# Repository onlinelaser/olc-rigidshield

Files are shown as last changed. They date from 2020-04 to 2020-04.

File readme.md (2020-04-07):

## RIGIDSHIELD v1

This is a disposable and/or reusable face shield design, that is 95% laser cut.

It's based strongly on a design from a US university that I can no longer find. If it's yours please raise a pull request so I can attribute it properly!

Our modifications based on hospital feedback have included:

1) Increasing the wrap of the shield

2) Adding a top cover to help reduce liquid penetration to the face

3) Changing the arm details to reduce a failure point on the acrylic and increase the range of head sizes it fits.

4) Adding an optional adhesive foam strip to the headband to make it more comfortable

5) Changing to 3mm Acrylic to make it lighter, cheaper and faster to cut

**Note that this is not an approved medical or protective device and has not been tested or certified as fit for any restricted use.**

## Source attribution
Original design - Unknown  
This variant - Online Laser Cutting

## License
Open Source Hardware

## Sterilising protocol
Bleaching is recomended.  
Not suitable for repeated Alcohol sanitisation, acrylic is typically ok in 30% or less alchol solutions but is prone to cracking at higher concentrations.

Ideally the rubber bumper and rubber band would be replaced each use.

## Lifespan:
Single or Multiple use depending on sterilising protocol used. 

## BOM
* 1 x 0.75mm PETG faceplate
* 1 x 3mm Acrylic head frame
* 1 x 0.75mm PETG Top plate
* 1 x Rubber strap/Rubber band
* 1 x Self Adhesive rubber forehead bumper (eg a short strip of window draft stopper)

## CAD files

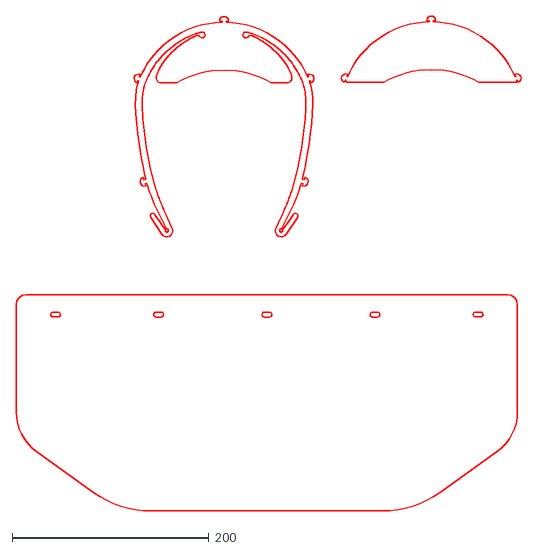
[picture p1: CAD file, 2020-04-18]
Rigid Frame.dxf
514.4 x 503.5

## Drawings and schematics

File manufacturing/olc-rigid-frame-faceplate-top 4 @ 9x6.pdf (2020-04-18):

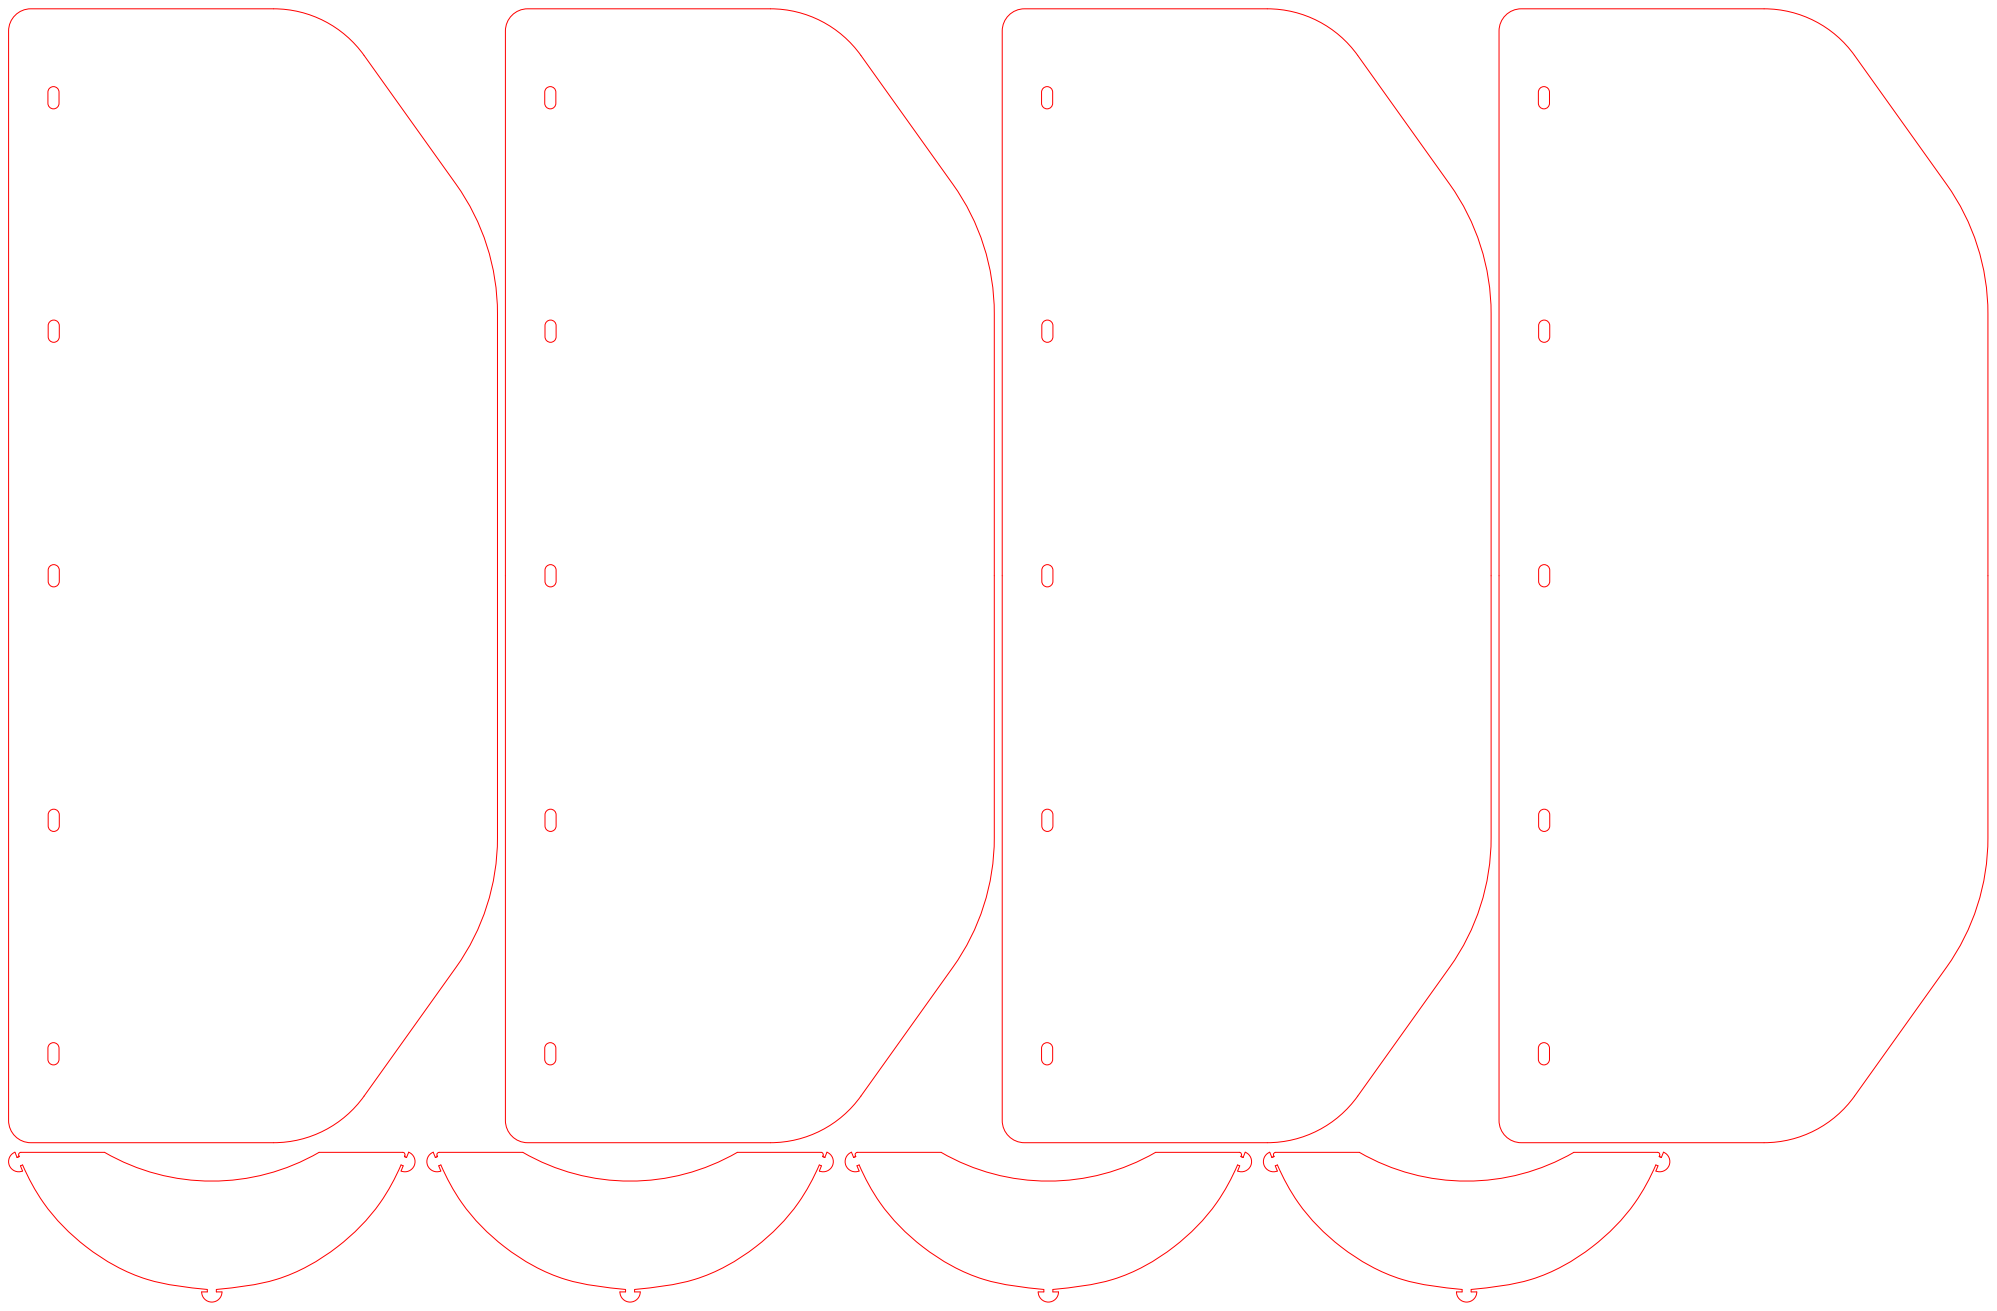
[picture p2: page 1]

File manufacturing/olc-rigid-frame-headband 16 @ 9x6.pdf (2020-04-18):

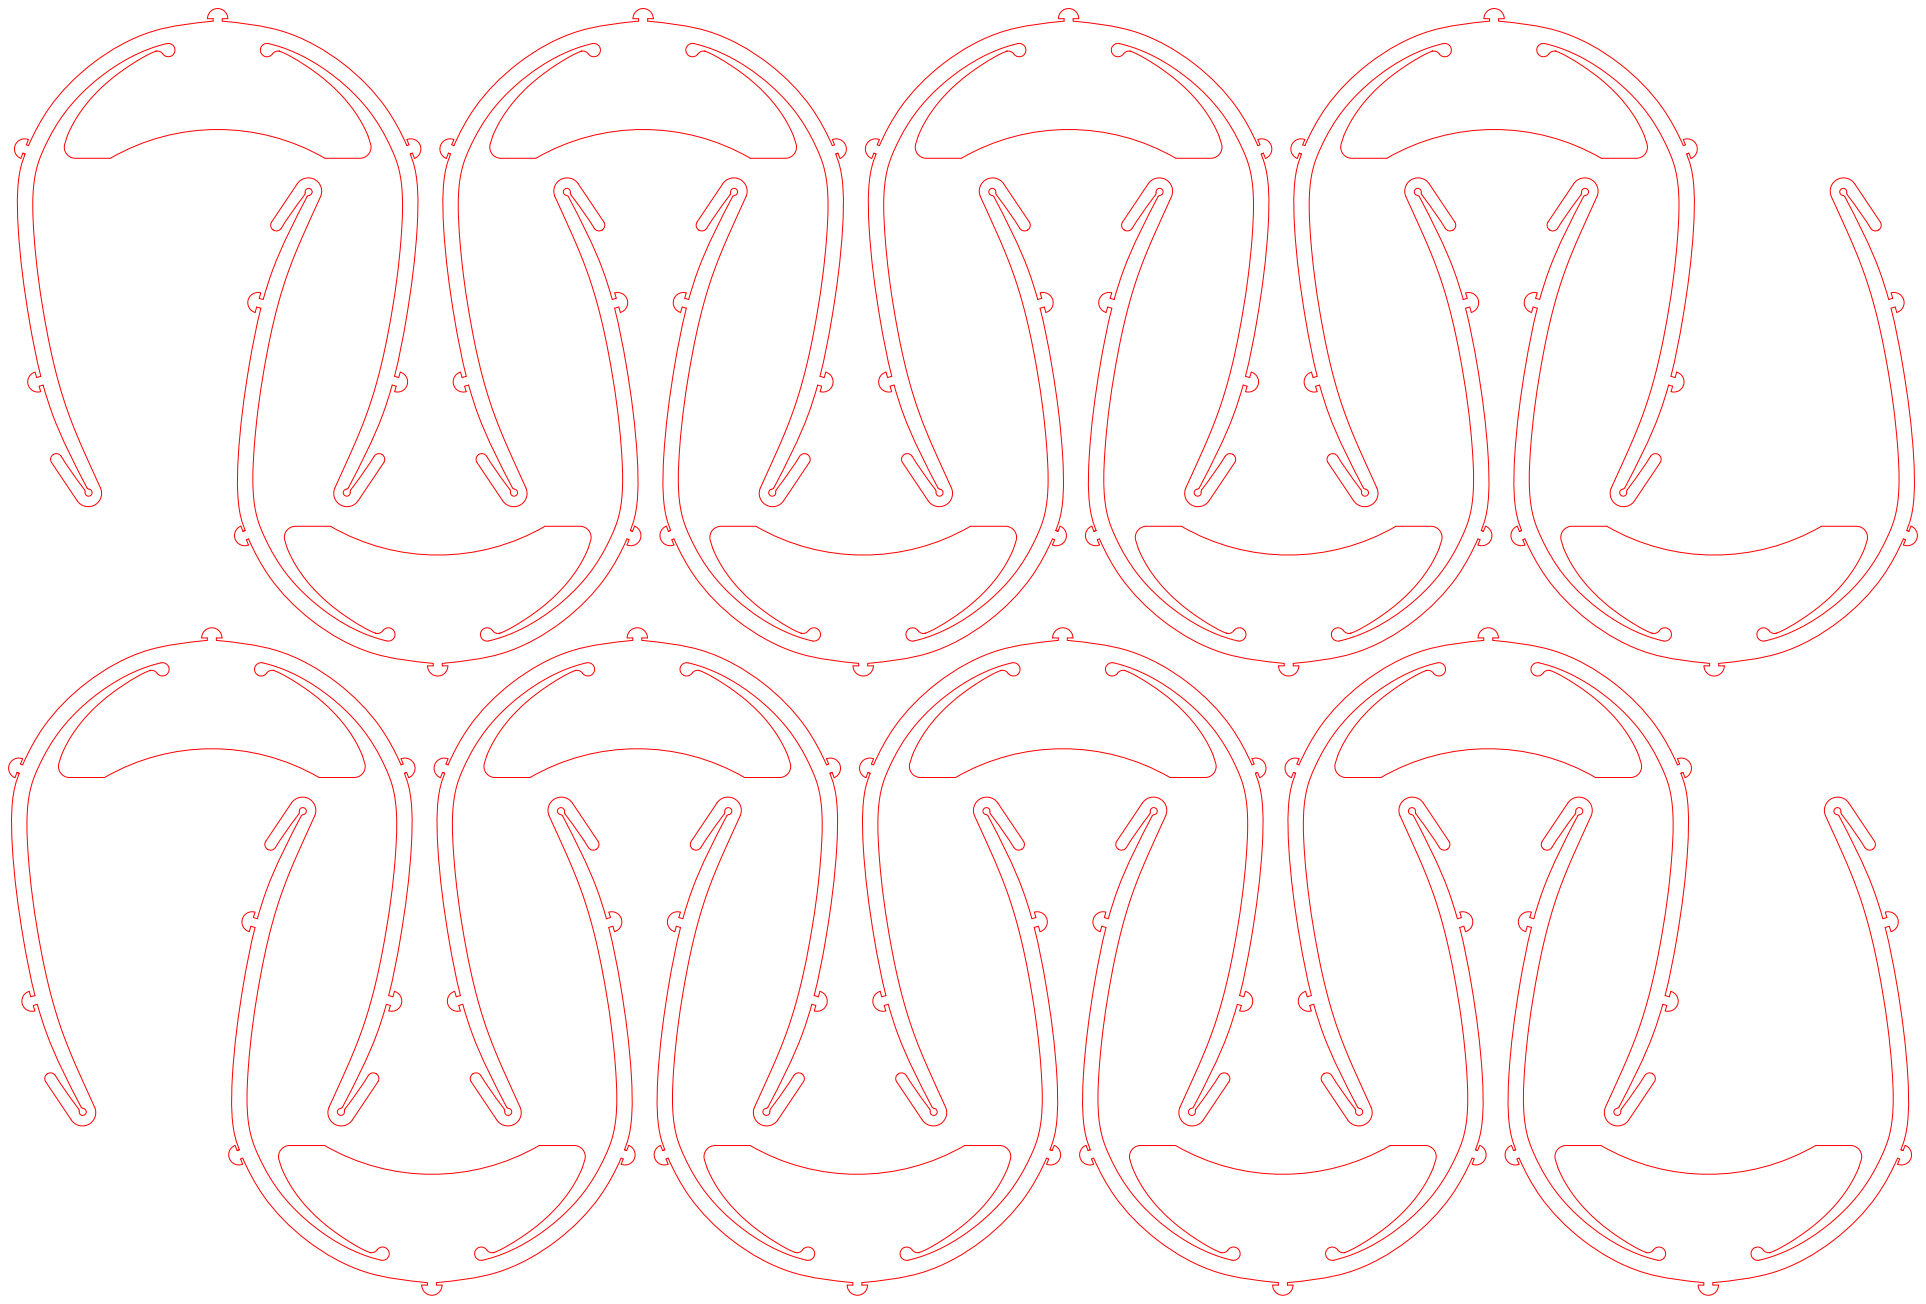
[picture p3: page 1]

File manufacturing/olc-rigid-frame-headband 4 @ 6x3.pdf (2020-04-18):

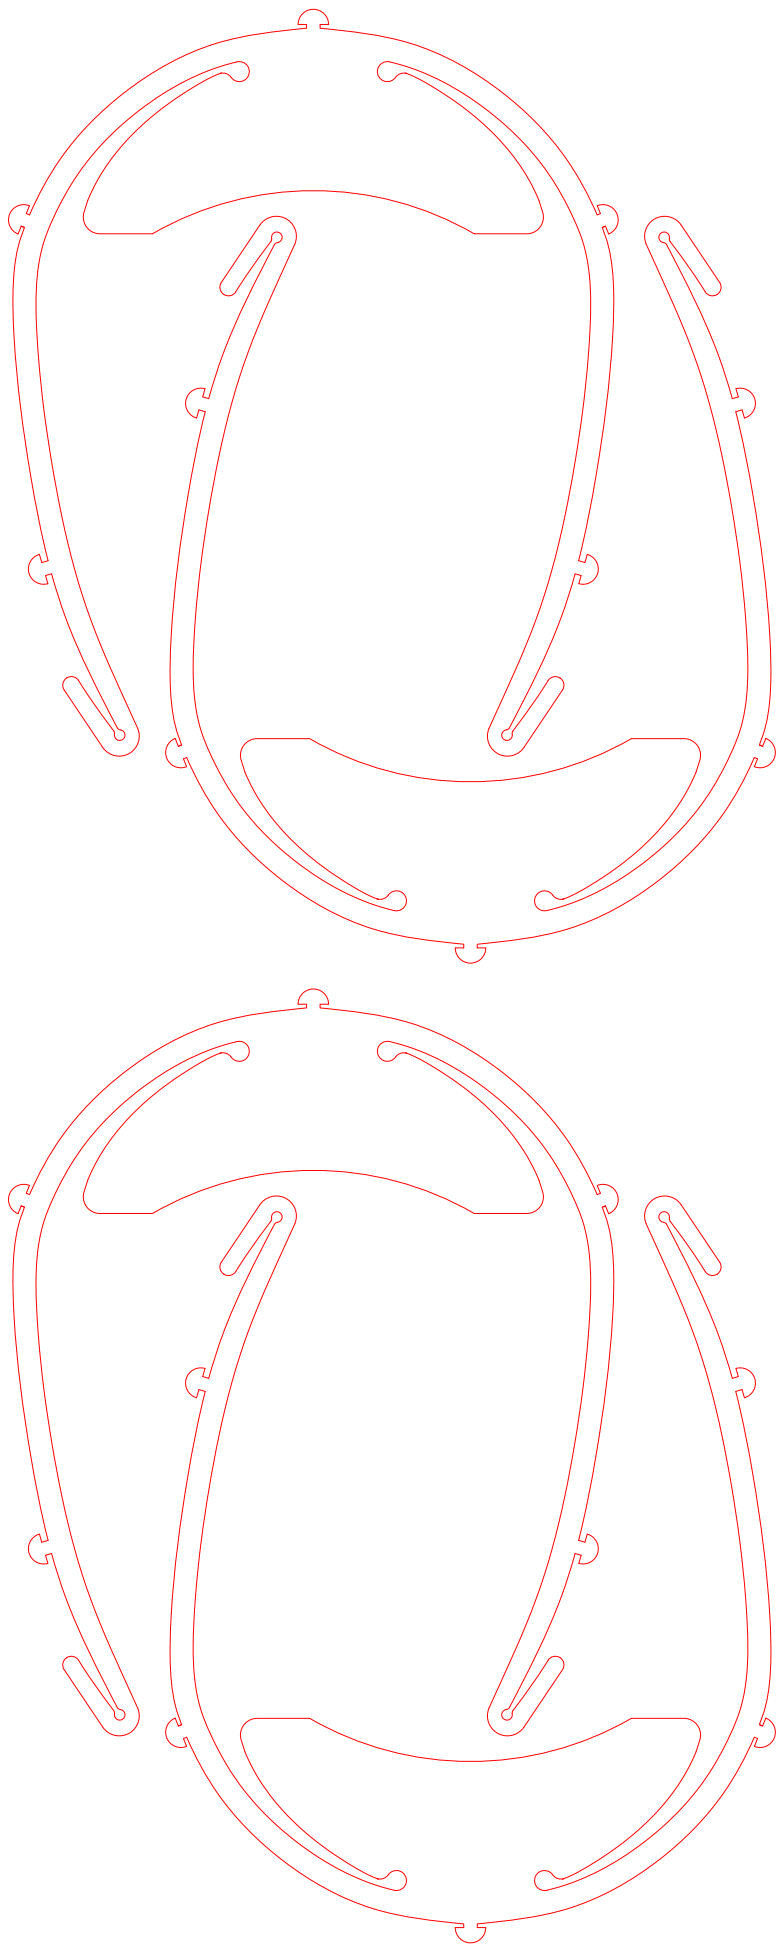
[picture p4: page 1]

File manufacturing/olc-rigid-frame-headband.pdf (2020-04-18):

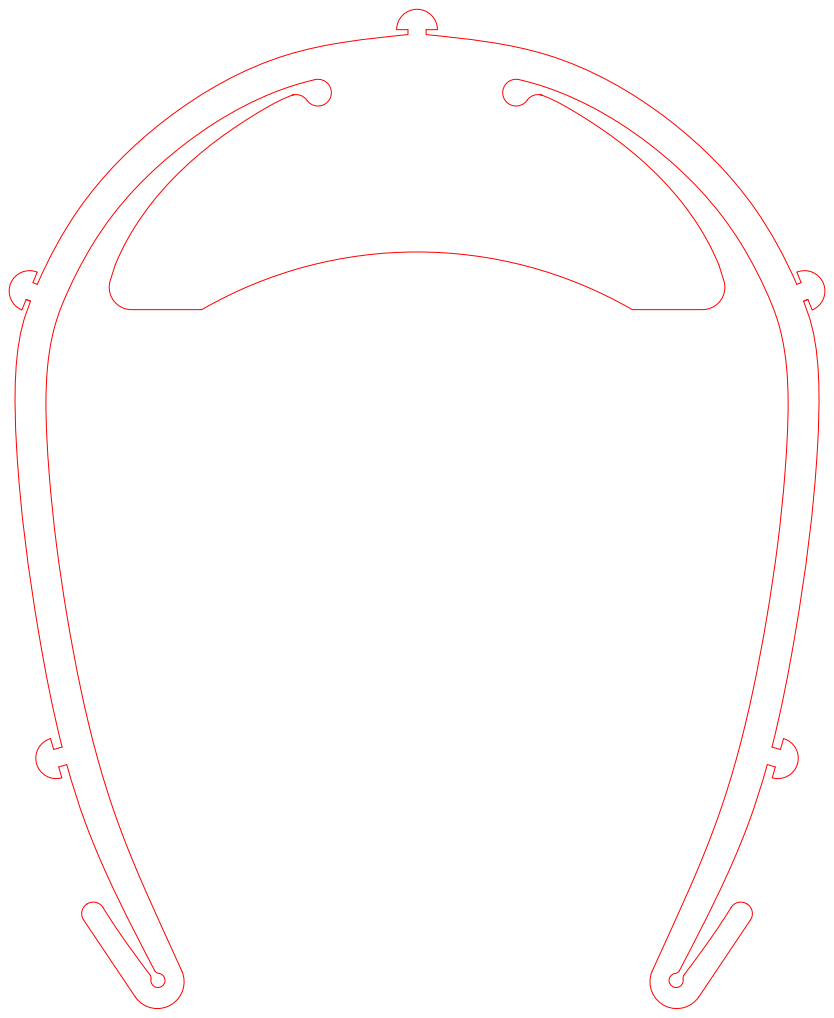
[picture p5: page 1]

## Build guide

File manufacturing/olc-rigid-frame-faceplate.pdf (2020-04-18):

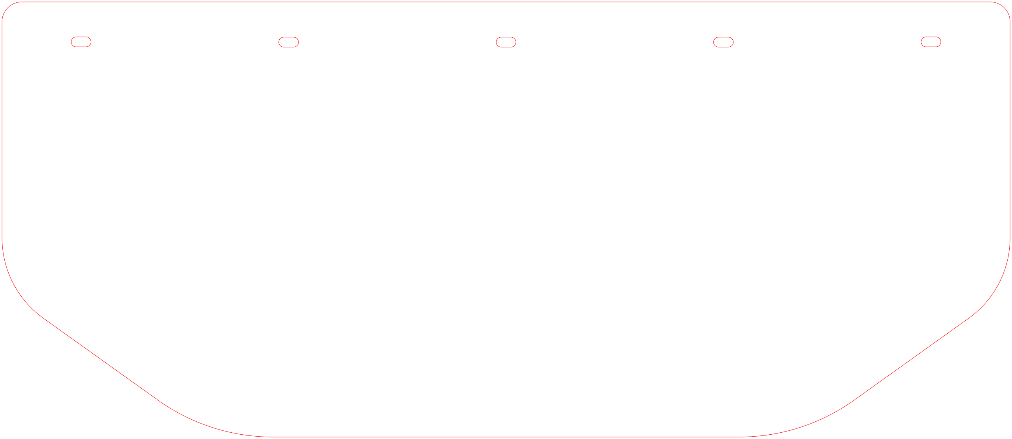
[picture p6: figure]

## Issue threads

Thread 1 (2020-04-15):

Improve impact resistance

onlinelaser, 2020-04-15:
If the item is dropped it tends to crack at the front with the crack starting from the flex holes

onlinelaser, 2020-04-17:
Tried using 3mm PETG for the top frame, this survives multiple drops but transfers the impact to the faceplate which cracks instead.

Also increases material costs.

It should probably work well if the faceplate was 0.1mm polyester, but that is less reusable.

onlinelaser, 2020-04-23:
Also can crack when removed roughly from the head, typically when pulled off with one hand

samori81, 2020-04-23:
A breaking strain of 6.37 Newtons was measured pulling the two side arms apart. The piece broke when deflected 85mm from relaxed. 3mm white acrylic was used.

onlinelaser, 2020-04-23:
Can you try the same file in 4.5mm acrylic and if you have it 3mm Petg please?

samori81, 2020-04-23:
A breaking strain of 10.7 Newtons was measured pulling the two side arms apart. The piece broke when deflected 22mm from relaxed. 4.5mm white acrylic was used.

samori81, 2020-04-23:
> Can you try the same file in 4.5mm acrylic and if you have it 3mm Petg please?
We only have 0.75mm PETG I'm afraid.

samori81, 2020-04-27:
When testing the altered design named facehugger a breaking strain of 7.8 Newtons was measured pulling the two side arms apart. The piece broke when deflected 260mm from relaxed. 3mm white acrylic was used.
